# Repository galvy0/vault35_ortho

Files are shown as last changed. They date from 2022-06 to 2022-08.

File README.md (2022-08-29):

# Vault35 Ortho PCB
Ortho version of Cain's Vault35 keyboard.  
Check out the original product and other awesome projects of Cain at [https://mechvault.net/](https://mechvault.net/).  

### Current Progress
PCB has been tested and is good to go.  
Now working on plates.  
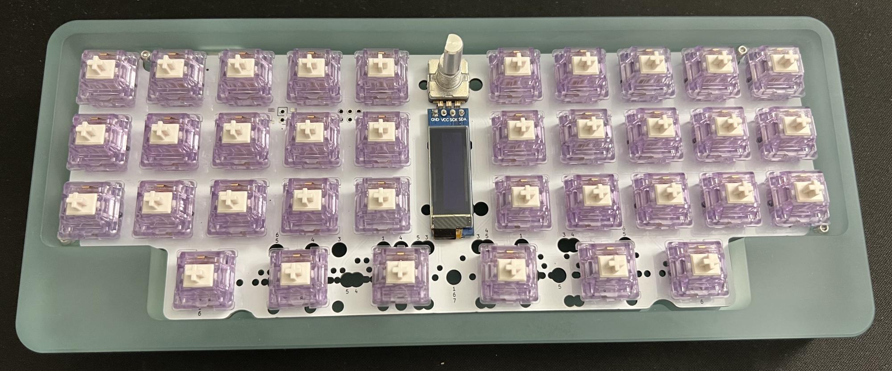
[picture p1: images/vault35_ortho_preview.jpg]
Preview


## PCB
### PCB Renders
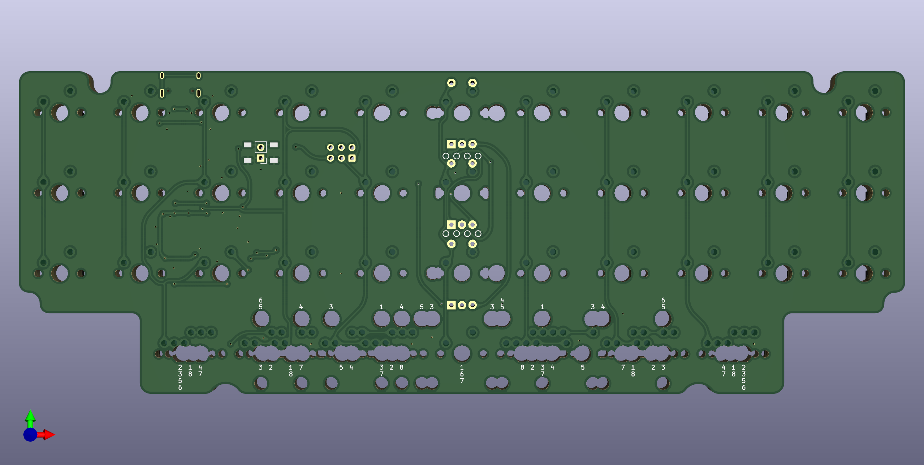
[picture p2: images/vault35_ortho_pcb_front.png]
Front

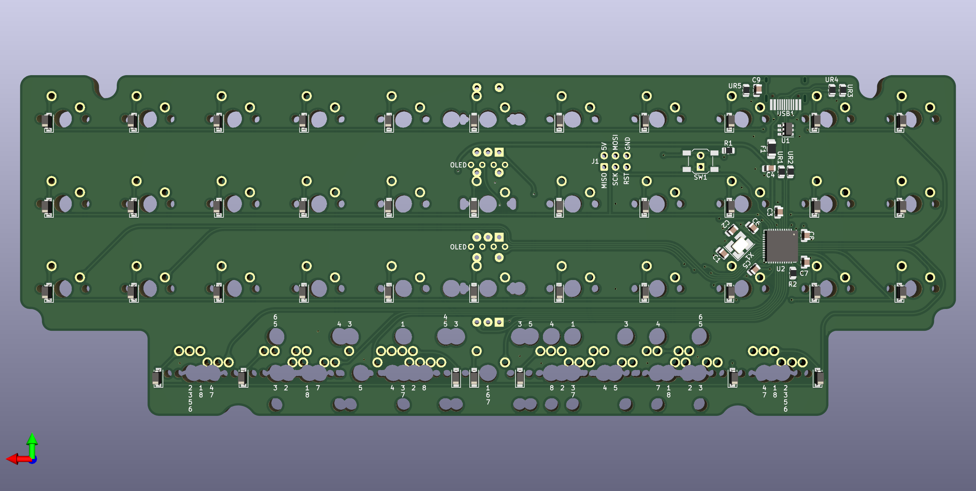
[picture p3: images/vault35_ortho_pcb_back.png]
Back


### Layout Options
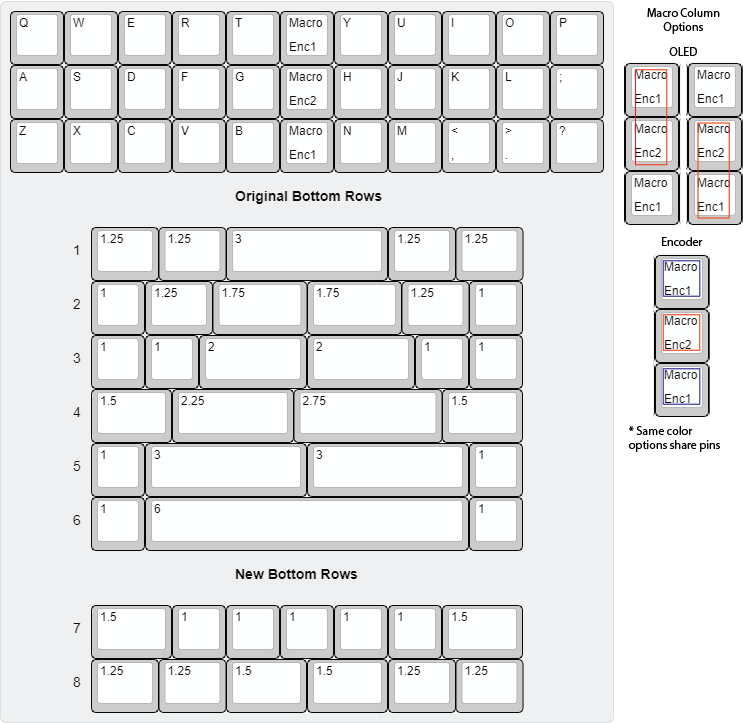
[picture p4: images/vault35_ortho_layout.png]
Layouts


## Plate
Many plate configurations are possible depending on the use of the middle column.  
Various plate options can be found in plates folder.  
This is the most inclusive version, which supports every configuration except 3u stabs on macro column:  
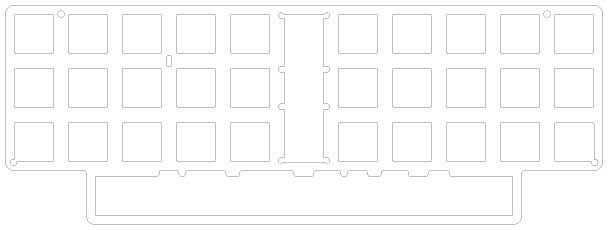
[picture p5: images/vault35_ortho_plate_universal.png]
Plate


## Firmware
https://github.com/galvy0/qmk_firmware/tree/galvy/keyboards/galvy/vault35_ortho

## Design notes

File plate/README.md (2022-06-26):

# Plate files for ortho Vault35

**Disclaimer: I am still in the process of ordering the plates, so I cannot guarantee that these plates will work.  

Multiple configurations are possible depending on your usage of the bottom layout and the middle macro column.  
A universal bottom row is compatible with all bottom row options.  
For normal switches and/or rotary encoder in the macro column, you can use the 1U plate.  
If you'd like to use an OLED, you can use either of the OLED plates.  
The universal plate would be compatible with all of the configurations, except for using 3U stabs in the macro column.  

## Plate layer and acrylic cover for OLED
Since the OLED is designed to sit underneath the plate, it would be recessed below the keycaps.  
To make it look nicer, I made an acrylic cover for the OLED (works for both top and bottom configuration), which works with M2 screws and ~3mm M2 spacers.  
 
Also, with the OLED being narrower than the switch cutout, the universal plate would leave a relatively large window if used with an OLED.  
To get around that, I made a small plate layer to add on top of the universal layer that would provide coverage of the gap.  
This plate layer would go underneath the spacer between the plate and the acrylic cover.  
  
So the final OLED layers for universal OLED plate option would be: M2 screw - plate - OLED plate layer - 3mm M2 spacer - acrylic cover - M2 screw.

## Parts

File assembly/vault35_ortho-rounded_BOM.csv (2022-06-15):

Id | Designator | Package | Quantity | Designation | Supplier and ref
1 | K_SPACE4,K_SPACE17,K_SPACE30,K_SPACE41,K_SPACE45,K_SPACE9,K_SPACE21,K_SPACE33,K_SPACE29,K_SPACE37,K_SPACE15,K_SPACE28,K_SPACE39,K_SPACE10,K_SPACE2,K_SPACE14,K_SPACE32,K_SPACE26,K_SPACE36,K_SPACE25,K_SPACE38,K_SPACE8,K_SPACE35,K_SPACE20,K_SPACE46,K_SPACE11,K_SPACE19,K_SPACE23,K_SPACE16,K_SPACE12,K_SPACE22,K_SPACE3,K_SPACE7,K_SPACE6,K_SPACE5,K_SPACE27,K_SPACE24,K_SPACE18,K_SPACE31,K_SPACE1,K_SPACE42,K_SPACE13 | MXOnly-1U-NoLED | 42 | KEYSW
2 | SW5 | PinHeader_1x02_P2.54mm_Vertical | 1 | SW_PUSH
3 | K_SPACE54,K_SPACE55,K_SPACE53,K_SPACE52,K_SPACE56,K_SPACE49 | MXOnly-1.25U-NoLED | 6 | KEYSW
4 | K_SPACE51,K_SPACE50 | MXOnly-1.75U-NoLED | 2 | KEYSW
5 | K_SPACE43,K_SPACE44 | MXOnly-2U-ReversedStabilizers-NoLED | 2 | KEYSW
6 | K_SPACE60,K_SPACE34,K_SPACE61,K_SPACE40 | MXOnly-1.5U-NoLED | 4 | KEYSW
7 | K_SPACE47 | MXOnly-2.25U-ReversedStabilizers-NoLED | 1 | KEYSW
8 | K_SPACE59,K_SPACE58,K_SPACE57 | MXOnly-3U-ReversedStabilizers-NoLED | 3 | KEYSW
9 | SW2,SW3,SW4 | RotaryEncoder_Alps_EC11E-Switch_Vertical_H20mm | 3 | RotaryEncoder_Switch
10 | SW6,SW1 | SW_SPST_SKQG_WithoutStem | 2 | SW_PUSH
11 | OL1,OL2 | OLED_v2 | 2 | OLED
12 | K_SPACE48 | MXOnly-2.75U-ReversedStabilizers-NoLED | 1 | KEYSW
13 | D_SPACE17,D_SPACE34,D_SPACE5,D_SPACE1,D_SPACE32,D_SPACE36,D_SPACE38,D_SPACE25,D_SPACE18,D_SPACE9,D_SPACE13,D_SPACE35,D_SPACE12,D_SPACE29,D_SPACE2,D_SPACE20,D_SPACE24,D_SPACE21,D_SPACE15,D_SPACE26,D_SPACE16,D_SPACE14,D_SPACE30,D_SPACE4,D_SPACE11,D_SPACE37,D_SPACE10,D_SPACE40,D_SPACE8,D_SPACE39,D_SPACE3,D_SPACE27,D_SPACE28,D_SPACE23,D_SPACE31,D_SPACE7,D_SPACE33,D_SPACE19,D_SPACE22,D_SPACE6 | D_SOD-123 | 40 | D
14 | X1 | Crystal_SMD_3225-4Pin_3.2x2.5mm_HandSoldering | 1 | Crystal_GND24_Small
15 | U1 | SOT-23-6 | 1 | SRV05-4
16 | UR5 | R_0805_2012Metric | 1 | 1M
17 | F1 | Fuse_1206_3216Metric_Pad1.42x1.75mm_HandSolder | 1 | Polyfuse_Small
18 | UR3,UR4 | R_0805_2012Metric | 2 | 5.1k
19 | U2 | QFN-44-1EP_7x7mm_P0.5mm_EP5.2x5.2mm | 1 | ATmega32U4-M
20 | C2,C1 | C_0805_2012Metric | 2 | 22p
21 | C4 | C_0805_2012Metric | 1 | 10uF
22 | UR1,UR2 | R_0805_2012Metric | 2 | 22
23 | R2,R1 | R_0805_2012Metric | 2 | 10k
24 | C6,C8,C5,C7 | C_0805_2012Metric | 4 | 0.1uf
25 | C3 | C_0805_2012Metric | 1 | 1uf
26 | C9 | C_0805_2012Metric | 1 | 4.7uF
27 | USB1 | HRO-TYPE-C-31-M-12-HandSoldering | 1 | HRO-TYPE-C-31-M-12
28 | J1 | IDC-Header_2x03_P2.54mm_Vertical | 1 | AVR-ISP-6

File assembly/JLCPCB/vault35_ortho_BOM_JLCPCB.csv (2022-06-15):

Comment | Designator | Footprint | JLCPCB Part (optional)
1N4148W | D_SPACE17,D_SPACE34,D_SPACE5,D_SPACE1,D_SPACE32,D_SPACE36,D_SPACE38,D_SPACE25,D_SPACE18,D_SPACE9,D_SPACE13,D_SPACE35,D_SPACE12,D_SPACE29,D_SPACE2,D_SPACE20,D_SPACE24,D_SPACE21,D_SPACE15,D_SPACE26,D_SPACE16,D_SPACE14,D_SPACE30,D_SPACE4,D_SPACE11,D_SPACE37,D_SPACE10,D_SPACE40,D_SPACE8,D_SPACE39,D_SPACE3,D_SPACE27,D_SPACE28,D_SPACE23,D_SPACE31,D_SPACE7,D_SPACE33,D_SPACE19,D_SPACE22,D_SPACE6 | SOD-123 | C81598
16 Mhz Crystal | X1 | SMD-3225_4P | C13738
SRV05-4 | U1 | SOT-23-6 | C85364
1M | UR5 | R0805 | C17514
1206L035/16YR | F1 | F1206 | C126817
5.1k | UR3,UR4 | R0805 | C27834
ATMEGA32U4 | U2 | VQFN-44_EP_7.0x7.0x0.5P | C112161
22pF | C2,C1 | C0805 | C1804
10uF | C4 | C0805 | C15850
22 | UR1,UR2 | R0805 | X
10k | R2,R1 | R0805 | C17414
0.1uF | C6,C8,C5,C7 | C0805 | C49678
1uF | C3 | C0805 | C91185
4.7uF | C9 | C0805 | C1779
HRO-TYPE-C-31-M-12 | USB1 | TYPE-C-31-M-12 | C165948

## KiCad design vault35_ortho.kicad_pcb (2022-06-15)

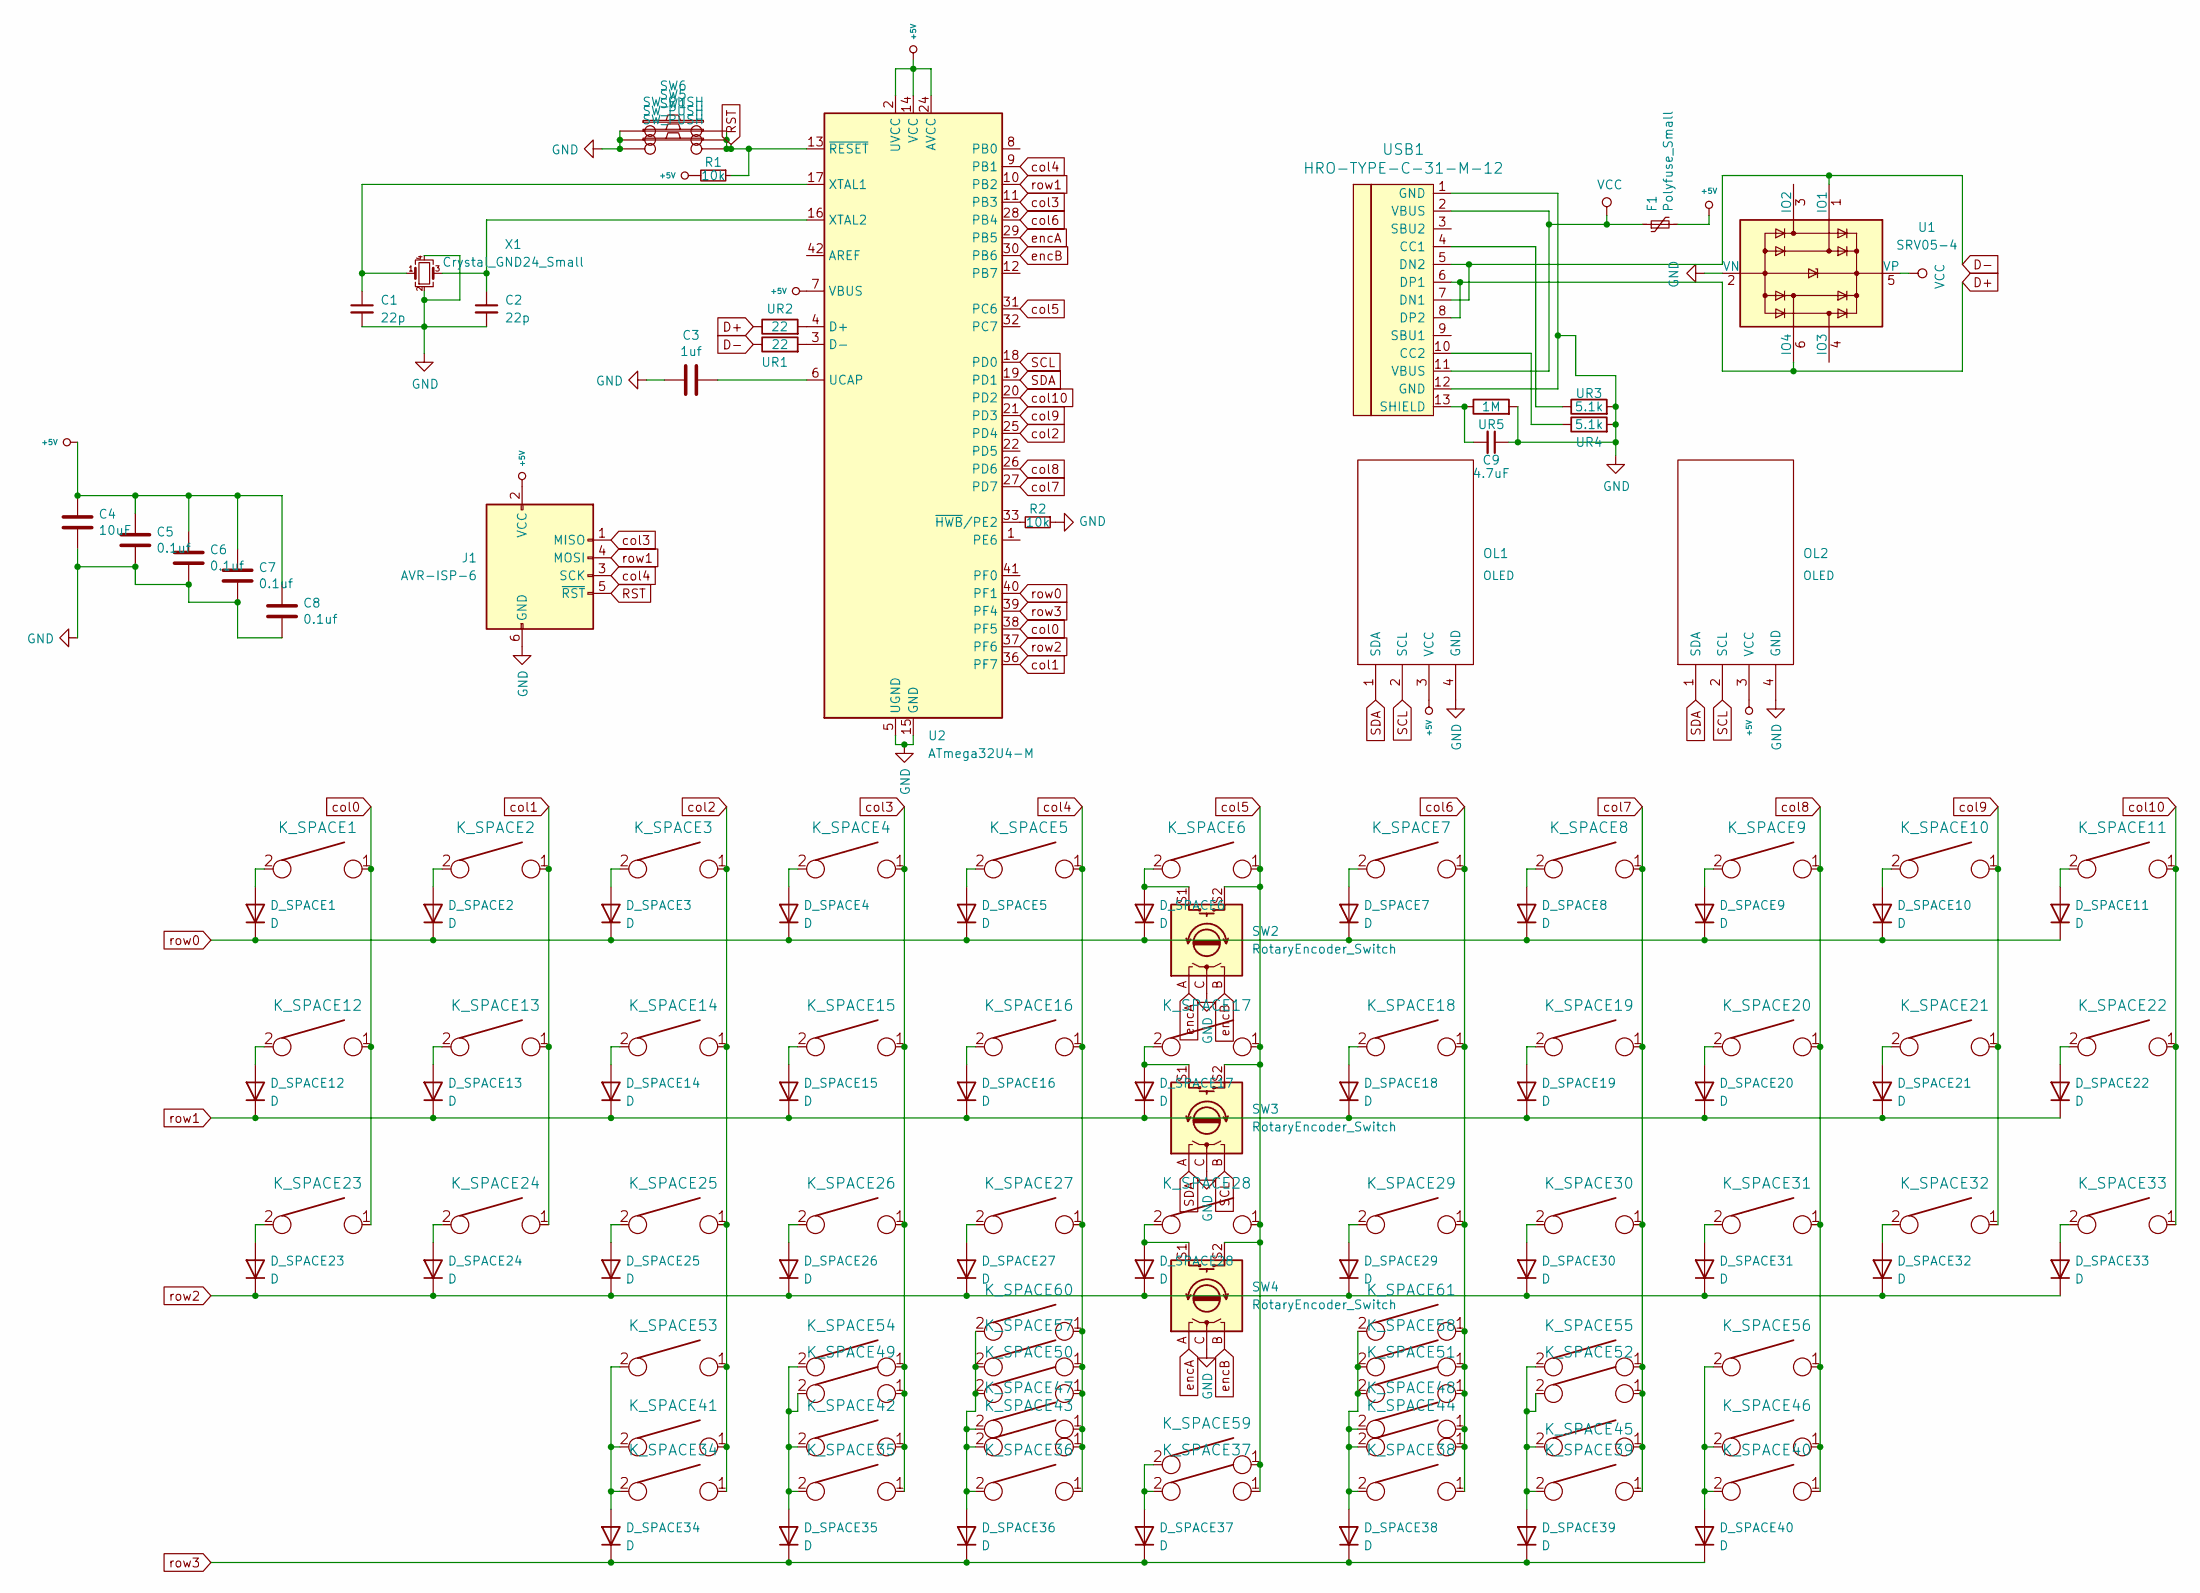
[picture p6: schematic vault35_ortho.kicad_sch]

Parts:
C1, C2: 22p; C_0805_2012Metric
C3: 1uf; C_0805_2012Metric
C4: 10uF; C_0805_2012Metric
C5, C6, C7, C8: 0.1uf; C_0805_2012Metric
C9: 4.7uF; C_0805_2012Metric
D_SPACE1, D_SPACE2, D_SPACE3, D_SPACE4, D_SPACE5, D_SPACE6, D_SPACE7, D_SPACE8, D_SPACE9, D_SPACE10, D_SPACE11, D_SPACE12, D_SPACE13, D_SPACE14, D_SPACE15, D_SPACE16, D_SPACE17, D_SPACE18, D_SPACE19, D_SPACE20, D_SPACE21, D_SPACE22, D_SPACE23, D_SPACE24, D_SPACE25, D_SPACE26, D_SPACE27, D_SPACE28, D_SPACE29, D_SPACE30, D_SPACE31, D_SPACE32, D_SPACE33, D_SPACE34, D_SPACE35, D_SPACE36, D_SPACE37, D_SPACE38, D_SPACE39, D_SPACE40: D; D_SOD-123
F1: Polyfuse_Small; Fuse_1206_3216Metric_Pad1.42x1.75mm_HandSolder
J1: AVR-ISP-6; IDC-Header_2x03_P2.54mm_Vertical
K_SPACE1, K_SPACE2, K_SPACE3, K_SPACE4, K_SPACE5, K_SPACE6, K_SPACE7, K_SPACE8, K_SPACE9, K_SPACE10, K_SPACE11, K_SPACE12, K_SPACE13, K_SPACE14, K_SPACE15, K_SPACE16, K_SPACE17, K_SPACE18, K_SPACE19, K_SPACE20, K_SPACE21, K_SPACE22, K_SPACE23, K_SPACE24, K_SPACE25, K_SPACE26, K_SPACE27, K_SPACE28, K_SPACE29, K_SPACE30, K_SPACE31, K_SPACE32, K_SPACE33, K_SPACE35, K_SPACE36, K_SPACE37, K_SPACE38, K_SPACE39, K_SPACE41, K_SPACE42, K_SPACE45, K_SPACE46: KEYSW; MXOnly-1U-NoLED
K_SPACE34, K_SPACE40, K_SPACE60, K_SPACE61: KEYSW; MXOnly-1.5U-NoLED
K_SPACE43, K_SPACE44: KEYSW; MXOnly-2U-ReversedStabilizers-NoLED
K_SPACE47: KEYSW; MXOnly-2.25U-ReversedStabilizers-NoLED
K_SPACE48: KEYSW; MXOnly-2.75U-ReversedStabilizers-NoLED
K_SPACE49, K_SPACE52, K_SPACE53, K_SPACE54, K_SPACE55, K_SPACE56: KEYSW; MXOnly-1.25U-NoLED
K_SPACE50, K_SPACE51: KEYSW; MXOnly-1.75U-NoLED
K_SPACE57, K_SPACE58, K_SPACE59: KEYSW; MXOnly-3U-ReversedStabilizers-NoLED
OL1, OL2: OLED; OLED_v2
R1, R2: 10k; R_0805_2012Metric
SW1, SW6: SW_PUSH; SW_SPST_SKQG_WithoutStem
SW2, SW3, SW4: RotaryEncoder_Switch; RotaryEncoder_Alps_EC11E-Switch_Vertical_H20mm
SW5: SW_PUSH; PinHeader_1x02_P2.54mm_Vertical
U1: SRV05-4; SOT-23-6
U2: ATmega32U4-M; QFN-44-1EP_7x7mm_P0.5mm_EP5.2x5.2mm
UR1, UR2: 22; R_0805_2012Metric
UR3, UR4: 5.1k; R_0805_2012Metric
UR5: 1M; R_0805_2012Metric
USB1: HRO-TYPE-C-31-M-12; HRO-TYPE-C-31-M-12-HandSoldering
X1: Crystal_GND24_Small; Crystal_SMD_3225-4Pin_3.2x2.5mm_HandSoldering

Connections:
+5V: C4.1, C5.1, C6.1, C7.1, C8.1, F1.2, J1.2 (VCC), OL1.3 (VCC), OL2.3 (VCC), R1.2, U2.2 (UVCC), U2.7 (VBUS), U2.14 (VCC), U2.24 (AVCC), U2.34 (VCC), U2.44 (AVCC)
D+: U1.6 (IO4), UR1.1, USB1.6 (DP1), USB1.8 (DP2)
D-: U1.1 (IO1), UR2.1, USB1.5 (DN2), USB1.7 (DN1)
GND: C1.2, C2.2, C3.2, C4.2, C5.2, C6.2, C7.2, C8.2, C9.1, J1.6 (GND), OL1.4 (GND), OL2.4 (GND), R2.1, SW1.1, SW2.C, SW3.C, SW4.C, SW5.1, SW6.1, U1.2 (VN), U2.5 (UGND), U2.15 (GND), U2.23 (GND), U2.35 (GND), U2.43 (GND), U2.45 (GND), UR3.2, UR4.2, UR5.2, USB1.1 (GND), USB1.12 (GND), X1.2, X1.4
unnamed: C1.1, U2.17 (XTAL1), X1.1
unnamed: C2.1, U2.16 (XTAL2), X1.3
unnamed: C3.1, U2.6 (UCAP)
unnamed: C9.2, UR5.1, USB1.13 (SHIELD)
unnamed: D_SPACE1.2 (A), K_SPACE1.2
unnamed: D_SPACE2.2 (A), K_SPACE2.2
unnamed: D_SPACE3.2 (A), K_SPACE3.2
unnamed: D_SPACE4.2 (A), K_SPACE4.2
unnamed: D_SPACE5.2 (A), K_SPACE5.2
unnamed: D_SPACE6.2 (A), K_SPACE6.2, SW2.S1
unnamed: D_SPACE7.2 (A), K_SPACE7.2
unnamed: D_SPACE8.2 (A), K_SPACE8.2
unnamed: D_SPACE9.2 (A), K_SPACE9.2
unnamed: D_SPACE10.2 (A), K_SPACE10.2
unnamed: D_SPACE11.2 (A), K_SPACE11.2
unnamed: D_SPACE12.2 (A), K_SPACE12.2
unnamed: D_SPACE13.2 (A), K_SPACE13.2
unnamed: D_SPACE14.2 (A), K_SPACE14.2
unnamed: D_SPACE15.2 (A), K_SPACE15.2
unnamed: D_SPACE16.2 (A), K_SPACE16.2
unnamed: D_SPACE17.2 (A), K_SPACE17.2, SW3.S1
unnamed: D_SPACE18.2 (A), K_SPACE18.2
unnamed: D_SPACE19.2 (A), K_SPACE19.2
unnamed: D_SPACE20.2 (A), K_SPACE20.2
unnamed: D_SPACE21.2 (A), K_SPACE21.2
unnamed: D_SPACE22.2 (A), K_SPACE22.2
unnamed: D_SPACE23.2 (A), K_SPACE23.2
unnamed: D_SPACE24.2 (A), K_SPACE24.2
unnamed: D_SPACE25.2 (A), K_SPACE25.2
unnamed: D_SPACE26.2 (A), K_SPACE26.2
unnamed: D_SPACE27.2 (A), K_SPACE27.2
unnamed: D_SPACE28.2 (A), K_SPACE28.2, SW4.S1
unnamed: D_SPACE29.2 (A), K_SPACE29.2
unnamed: D_SPACE30.2 (A), K_SPACE30.2
unnamed: D_SPACE31.2 (A), K_SPACE31.2
unnamed: D_SPACE32.2 (A), K_SPACE32.2
unnamed: D_SPACE33.2 (A), K_SPACE33.2
unnamed: D_SPACE34.2 (A), K_SPACE34.2, K_SPACE41.2, K_SPACE53.2
unnamed: D_SPACE35.2 (A), K_SPACE35.2, K_SPACE42.2, K_SPACE49.2, K_SPACE54.2
unnamed: D_SPACE36.2 (A), K_SPACE36.2, K_SPACE43.2, K_SPACE47.2, K_SPACE50.2, K_SPACE57.2, K_SPACE60.2
unnamed: D_SPACE37.2 (A), K_SPACE37.2, K_SPACE59.2
unnamed: D_SPACE38.2 (A), K_SPACE38.2, K_SPACE44.2, K_SPACE48.2, K_SPACE51.2, K_SPACE58.2, K_SPACE61.2
unnamed: D_SPACE39.2 (A), K_SPACE39.2, K_SPACE45.2, K_SPACE52.2, K_SPACE55.2
unnamed: D_SPACE40.2 (A), K_SPACE40.2, K_SPACE46.2, K_SPACE56.2
unnamed: R2.2, U2.33 (~HWB/PE2)
unnamed: U2.3 (D-), UR2.2
unnamed: U2.4 (D+), UR1.2
unnamed: UR3.1, USB1.4 (CC1)
unnamed: UR4.1, USB1.10 (CC2)
RST: J1.5 (~RST), R1.1, SW1.2, SW5.2, SW6.2, U2.13 (~RESET)
SCL: OL1.2 (SCL), OL2.2 (SCL), SW3.B, U2.18 (PD0)
SDA: OL1.1 (SDA), OL2.1 (SDA), SW3.A, U2.19 (PD1)
VCC: F1.1, U1.5 (VP), USB1.2 (VBUS), USB1.11 (VBUS)
col0: K_SPACE1.1, K_SPACE12.1, K_SPACE23.1, U2.38 (PF5)
col1: K_SPACE2.1, K_SPACE13.1, K_SPACE24.1, U2.36 (PF7)
col2: K_SPACE3.1, K_SPACE14.1, K_SPACE25.1, K_SPACE34.1, K_SPACE41.1, K_SPACE53.1, U2.25 (PD4)
col3: J1.1 (MISO), K_SPACE4.1, K_SPACE15.1, K_SPACE26.1, K_SPACE35.1, K_SPACE42.1, K_SPACE49.1, K_SPACE54.1, U2.11 (PB3)
col4: J1.3 (SCK), K_SPACE5.1, K_SPACE16.1, K_SPACE27.1, K_SPACE36.1, K_SPACE43.1, K_SPACE47.1, K_SPACE50.1, K_SPACE57.1, K_SPACE60.1, U2.9 (PB1)
col5: K_SPACE6.1, K_SPACE17.1, K_SPACE28.1, K_SPACE37.1, K_SPACE59.1, SW2.S2, SW3.S2, SW4.S2, U2.31 (PC6)
col6: K_SPACE7.1, K_SPACE18.1, K_SPACE29.1, K_SPACE38.1, K_SPACE44.1, K_SPACE48.1, K_SPACE51.1, K_SPACE58.1, K_SPACE61.1, U2.28 (PB4)
col7: K_SPACE8.1, K_SPACE19.1, K_SPACE30.1, K_SPACE39.1, K_SPACE45.1, K_SPACE52.1, K_SPACE55.1, U2.27 (PD7)
col8: K_SPACE9.1, K_SPACE20.1, K_SPACE31.1, K_SPACE40.1, K_SPACE46.1, K_SPACE56.1, U2.26 (PD6)
col9: K_SPACE10.1, K_SPACE21.1, K_SPACE32.1, U2.21 (PD3)
col10: K_SPACE11.1, K_SPACE22.1, K_SPACE33.1, U2.20 (PD2)
encA: SW2.A, SW4.A, U2.29 (PB5)
encB: SW2.B, SW4.B, U2.30 (PB6)
row0: D_SPACE1.1 (K), D_SPACE2.1 (K), D_SPACE3.1 (K), D_SPACE4.1 (K), D_SPACE5.1 (K), D_SPACE6.1 (K), D_SPACE7.1 (K), D_SPACE8.1 (K), D_SPACE9.1 (K), D_SPACE10.1 (K), D_SPACE11.1 (K), U2.40 (PF1)
row1: D_SPACE12.1 (K), D_SPACE13.1 (K), D_SPACE14.1 (K), D_SPACE15.1 (K), D_SPACE16.1 (K), D_SPACE17.1 (K), D_SPACE18.1 (K), D_SPACE19.1 (K), D_SPACE20.1 (K), D_SPACE21.1 (K), D_SPACE22.1 (K), J1.4 (MOSI), U2.10 (PB2)
row2: D_SPACE23.1 (K), D_SPACE24.1 (K), D_SPACE25.1 (K), D_SPACE26.1 (K), D_SPACE27.1 (K), D_SPACE28.1 (K), D_SPACE29.1 (K), D_SPACE30.1 (K), D_SPACE31.1 (K), D_SPACE32.1 (K), D_SPACE33.1 (K), U2.37 (PF6)
row3: D_SPACE34.1 (K), D_SPACE35.1 (K), D_SPACE36.1 (K), D_SPACE37.1 (K), D_SPACE38.1 (K), D_SPACE39.1 (K), D_SPACE40.1 (K), U2.39 (PF4)

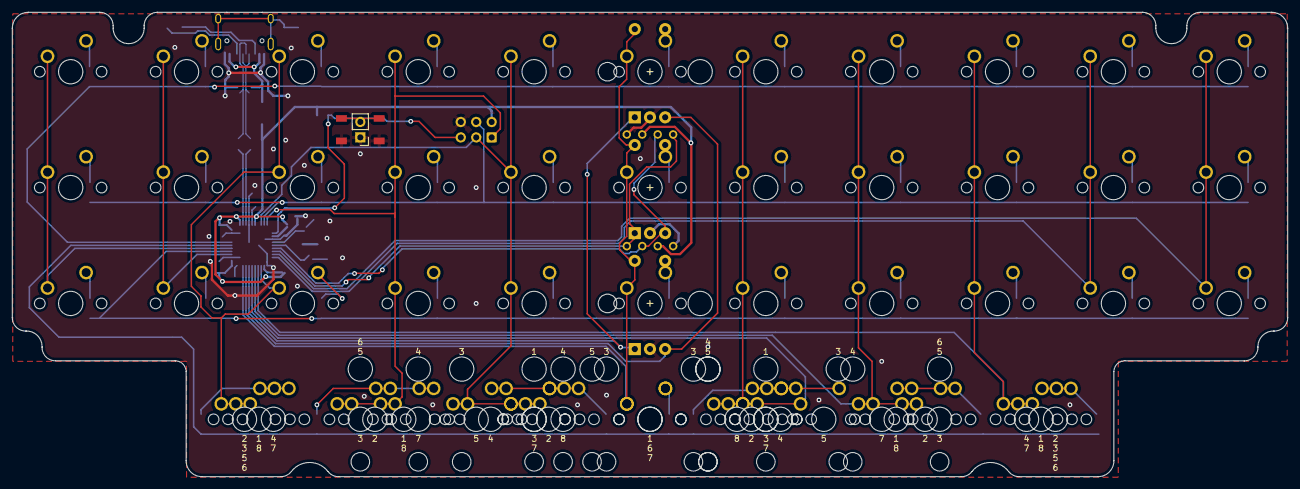
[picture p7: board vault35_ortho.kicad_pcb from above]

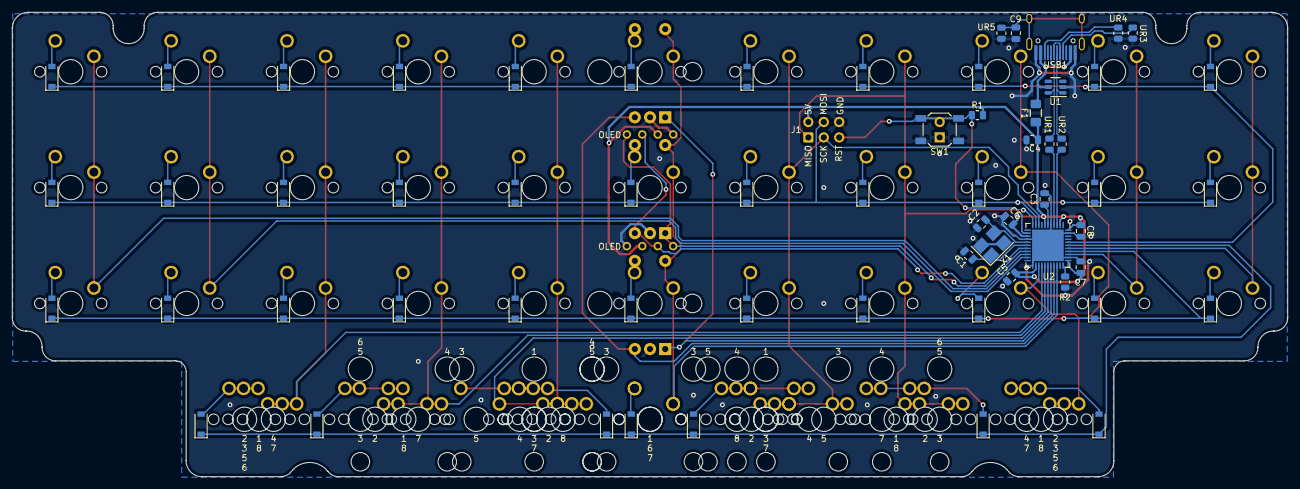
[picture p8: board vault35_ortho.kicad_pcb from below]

Board: 2 copper layers, 209.7 x 76.4 mm, 131 parts (63 on the bottom side), 74 nets.

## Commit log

2022-06-15 Update readme to contain current progress
2022-06-26 update oled related plate stuff
